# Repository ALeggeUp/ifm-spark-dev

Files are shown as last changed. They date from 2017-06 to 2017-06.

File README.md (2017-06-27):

# IFM Spark Dev Board

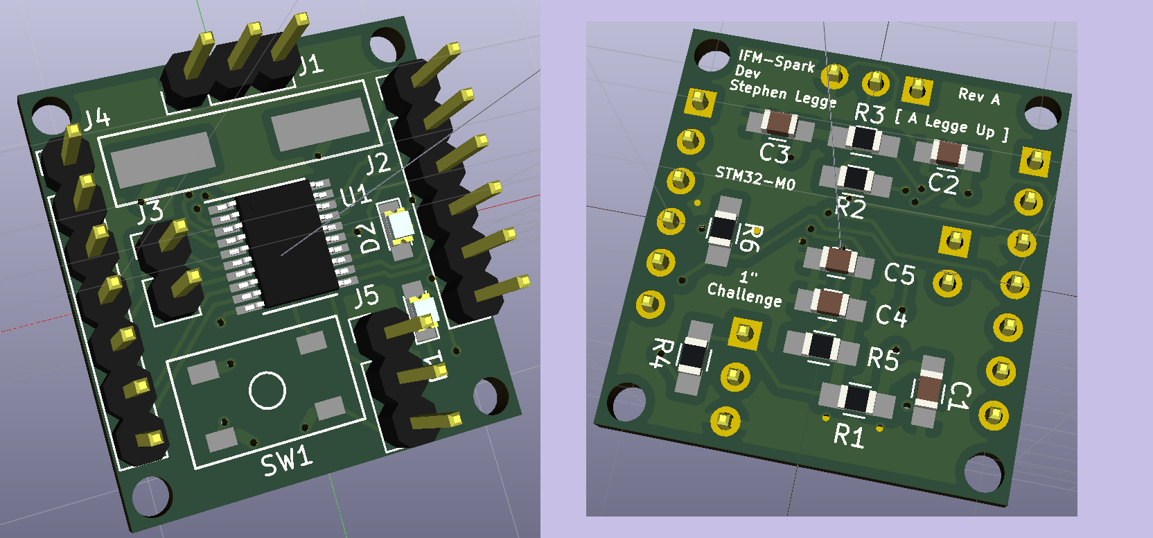
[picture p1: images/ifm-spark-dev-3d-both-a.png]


What is it?
-----------

IFM Spark Dev Board is a minimal Cortex-M0 dev board for experimentation.
The firmware is an example project that uses Gradle to build and test an embedded application.
It uses the examples included with the CppUTest project to show how it would work, the
embedded application doesn't do anything other than contain the objects to test.

Contributors
------------

* [Stephen Legge](https://github.com/slegge)

System requirements
-------------------

Gradle requires Java, but with the included gradlew that should be all that is needed
to build the firmware image.  This project as part of its initialization should pull
down the toolchain needed to build the firmware image.

For each operating system the requirements are similar, generally a Gcc or Clang
toolchain needs to be available for Gradle to use to build the tests.

In Windows, a standard install of Cygwin with gcc toolchain has been tested.

In Mac OS X, a default install of Xcode provides the Clang toolchain.

In Linux, standard gcc/g++ devel packages usually work fine.

Building
--------

If you have Gradle 3.0+ installed, you can just use

`gradle clean build`

or to use the bundled gradlew (Gradle Wrapper) use:

`./gradlew clean build`

Executing
---------

The Gradle build will create the firmware image and the CppUTest unit test runner.
The firmware image is meant to be loaded on the hardware, you'll need to load it
onto the hardware manually.  With an mbed board like a Nucleo board, it is just a
matter of copying the image to the mass storage device.

The CppUTest unit test runner is called utestrunner located under build/utestrunner/...

# License

This work is licensed under the Creative Commons Attribution 4.0 International License. To view a copy of this license, visit http://creativecommons.org/licenses/by/4.0/ or send a
letter to Creative Commons, PO Box 1866, Mountain View, CA 94042, USA.

Disclaimer
----------

THIS SOFTWARE IS PROVIDED BY THE COPYRIGHT HOLDERS AND CONTRIBUTORS "AS IS"
AND ANY EXPRESS OR IMPLIED WARRANTIES, INCLUDING, BUT NOT LIMITED TO, THE
IMPLIED WARRANTIES OF MERCHANTABILITY AND FITNESS FOR A PARTICULAR PURPOSE
ARE DISCLAIMED. IN NO EVENT SHALL THE COPYRIGHT OWNER OR CONTRIBUTORS BE
LIABLE FOR ANY DIRECT, INDIRECT, INCIDENTAL, SPECIAL, EXEMPLARY, OR
CONSEQUENTIAL DAMAGES (INCLUDING, BUT NOT LIMITED TO, PROCUREMENT OF
SUBSTITUTE GOODS OR SERVICES; LOSS OF USE, DATA, OR PROFITS; OR BUSINESS
INTERRUPTION) HOWEVER CAUSED AND ON ANY THEORY OF LIABILITY, WHETHER IN
CONTRACT, STRICT LIABILITY, OR TORT (INCLUDING NEGLIGENCE OR OTHERWISE)
ARISING IN ANY WAY OUT OF THE USE OF THIS SOFTWARE, EVEN IF ADVISED OF THE
POSSIBILITY OF SUCH DAMAGE.

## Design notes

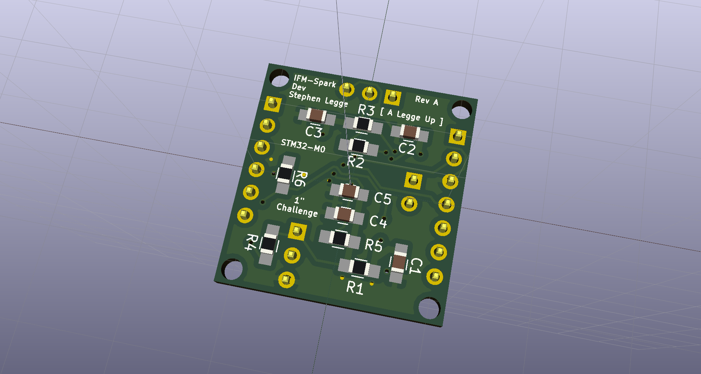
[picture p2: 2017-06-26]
images/ifm-spark-dev-3d-back-a.png

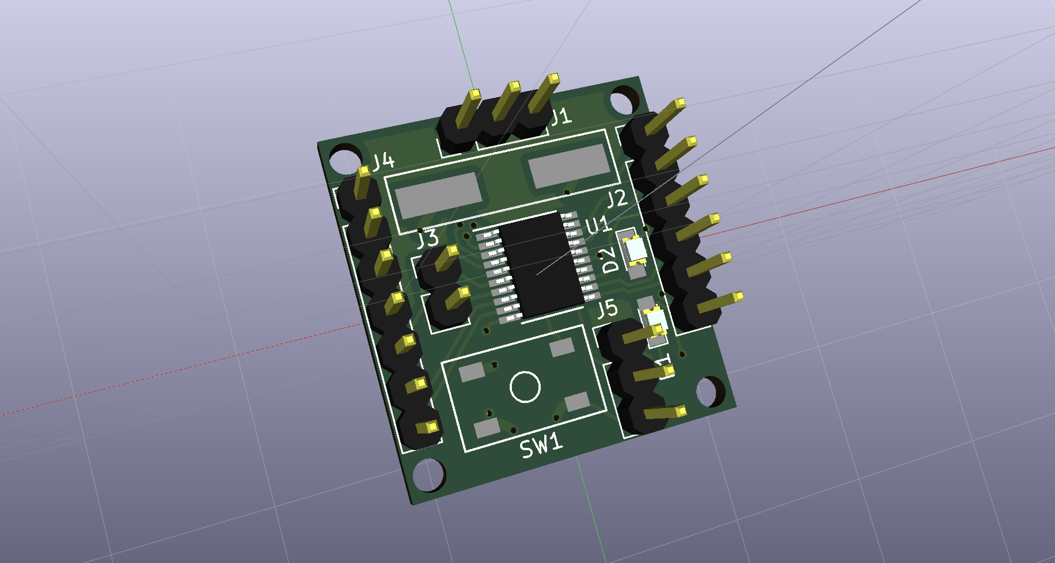
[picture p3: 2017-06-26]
images/ifm-spark-dev-3d-front-a.png

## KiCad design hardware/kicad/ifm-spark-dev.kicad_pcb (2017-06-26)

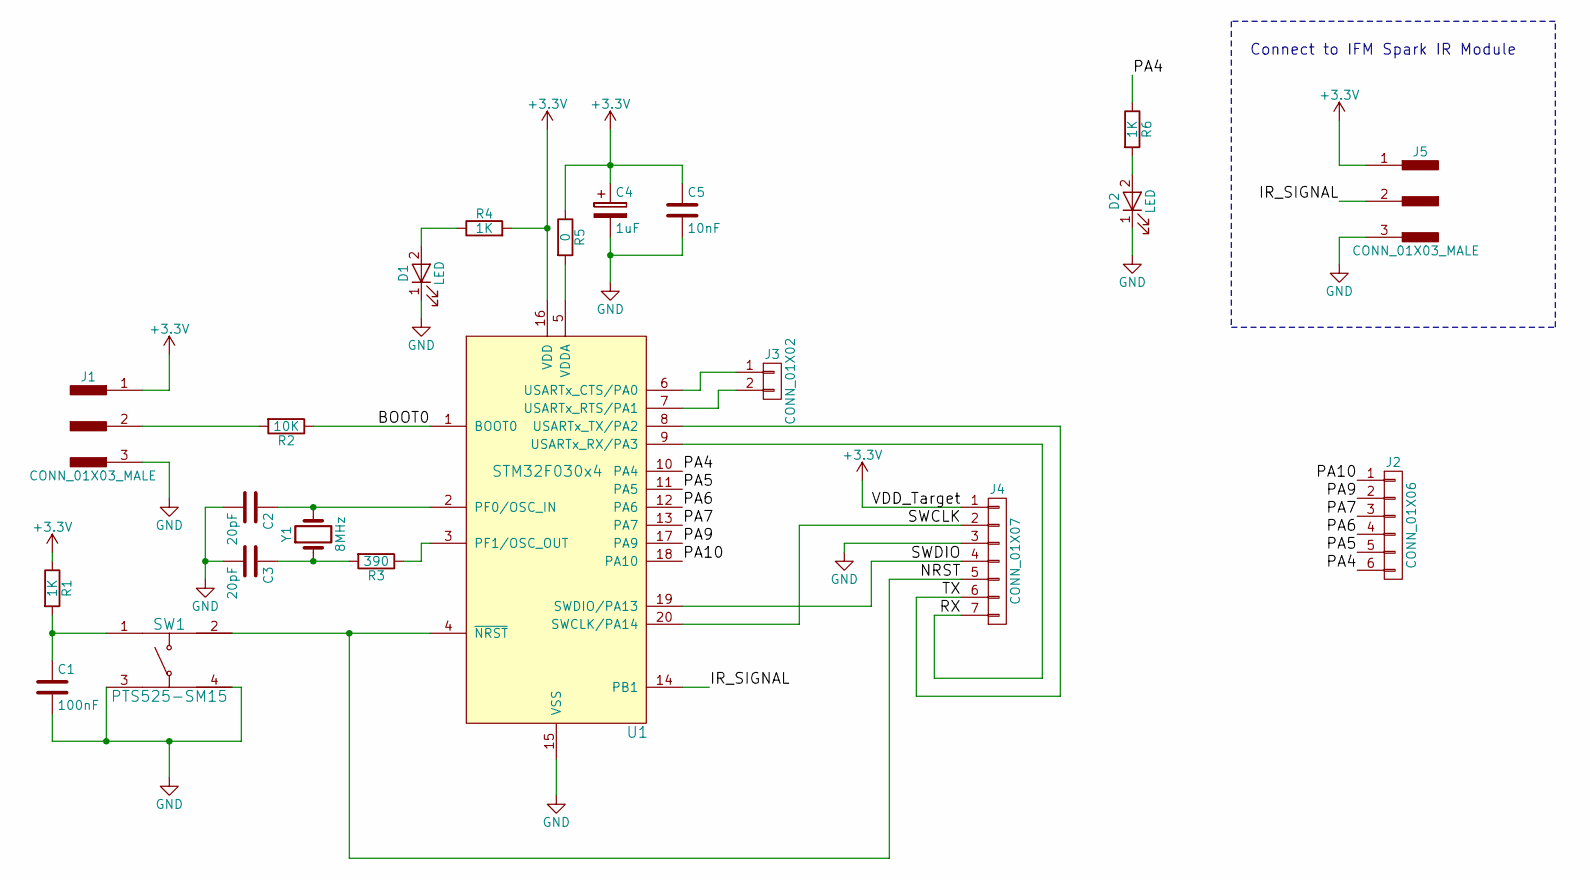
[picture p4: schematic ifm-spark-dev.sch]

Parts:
C1: 100nF; C_0805_HandSoldering
C2, C3: 20pF; C_0805_HandSoldering
C4: 1uF; C_0805_HandSoldering
C5: 10nF; C_0805_HandSoldering
D1, D2: LED; LED_0805
J1, J5: CONN_01X03_MALE; Pin_Header_Straight_1x03_Pitch2.54mm
J2: CONN_01X06; Pin_Header_Straight_1x06_Pitch2.54mm
J3: CONN_01X02; Pin_Header_Straight_1x02_Pitch2.54mm
J4: CONN_01X07; Pin_Header_Straight_1x07_Pitch2.54mm
R1, R4, R6: 1K; R_0805_HandSoldering
R2: 10K; R_0805_HandSoldering
R3: 390; R_0805_HandSoldering
R5: 0; R_0805_HandSoldering
SW1: PTS525-SM15; PTS525_SM15_SMTR2_LFS; MPN PTS525SM15SMTR2 LFS
U1: STM32F030x4; TSSOP-20_4.4x6.5mm_Pitch0.65mm; MPN STM32F030F4P6
Y1: 8MHz; ABLS-8.000MHZ-B4-T; MPN ABLS-8.000MHZ-B4-T

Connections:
+3V3: C4.1, C5.1, J1.1, J4.1, J5.1, R1.1, R4.2, R5.1, U1.16 (VDD)
/BOOT0: R2.1, U1.1 (BOOT0)
/IR_SIGNAL: J5.2, U1.14 (PB1)
/NRST: J4.5, SW1.2, U1.4 (~NRST)
/PA4: J2.6, R6.1, U1.10 (PA4)
/PA5: J2.5, U1.11 (PA5)
/PA6: J2.4, U1.12 (PA6)
/PA7: J2.3, U1.13 (PA7)
/PA9: J2.2, U1.17 (PA9)
/PA10: J2.1, U1.18 (PA10)
/RX: J4.7, U1.9 (USARTx_RX/PA3)
/SWCLK: J4.2, U1.20 (SWCLK/PA14)
/SWDIO: J4.4, U1.19 (SWDIO/PA13)
/TX: J4.6, U1.8 (USARTx_TX/PA2)
GND: C1.2, C2.2, C3.2, C4.2, C5.2, D1.1 (K), D2.1 (K), J1.3, J4.3, J5.3, SW1.3, SW1.4, U1.15 (VSS)
unnamed: C1.1, R1.2, SW1.1
unnamed: C2.1, U1.2 (PF0/OSC_IN), Y1.2
unnamed: C3.1, R3.2, Y1.1
unnamed: D1.2 (A), R4.1
unnamed: D2.2 (A), R6.2
unnamed: J1.2, R2.2
unnamed: J3.1, U1.6 (USARTx_CTS/PA0)
unnamed: J3.2, U1.7 (USARTx_RTS/PA1)
unnamed: R3.1, U1.3 (PF1/OSC_OUT)
unnamed: R5.2, U1.5 (VDDA)

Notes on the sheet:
Connect to IFM Spark IR Module

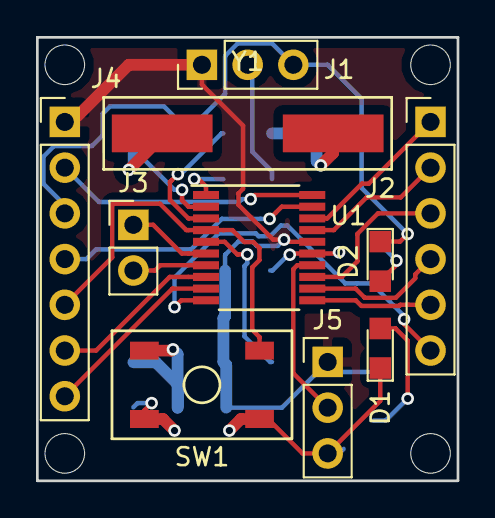
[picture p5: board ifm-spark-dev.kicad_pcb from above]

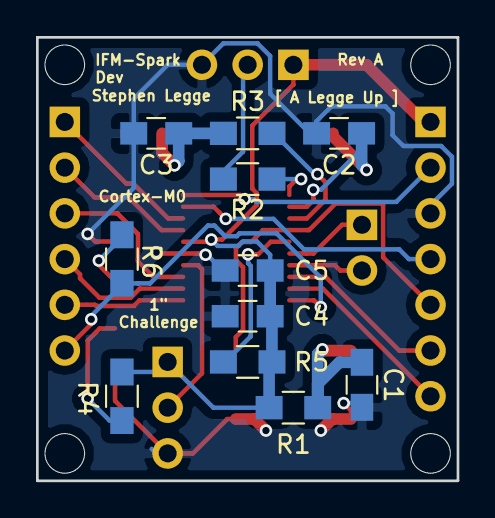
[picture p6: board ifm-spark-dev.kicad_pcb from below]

Board: 2 copper layers, 23.4 x 24.6 mm, 21 parts (11 on the bottom side), 25 nets.

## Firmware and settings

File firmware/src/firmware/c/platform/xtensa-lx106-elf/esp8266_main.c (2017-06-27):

#include <ets_sys.h>

#include "osapi.h"
#include "user_interface.h"

#include <os_type.h>
#include <gpio.h>
#include "driver/uart.h"

#define DELAY 1000

LOCAL os_timer_t hello_timer;
extern int ets_uart_printf(const char *fmt, ...);

LOCAL void ICACHE_FLASH_ATTR hello_cb(void *arg)
{
    ets_uart_printf("Hello World!\r\n");
}

/******************************************************************************
 * FunctionName : user_rf_cal_sector_set
 * Description  : SDK just reversed 4 sectors, used for rf init data and paramters.
 *                We add this function to force users to set rf cal sector, since
 *                we don't know which sector is free in user's application.
 *                sector map for last several sectors : ABBBCDDD
 *                A : rf cal
 *                B : at parameters
 *                C : rf init data
 *                D : sdk parameters
 * Parameters   : none
 * Returns      : rf cal sector
*******************************************************************************/
uint32 ICACHE_FLASH_ATTR
user_rf_cal_sector_set(void)
{
    enum flash_size_map size_map = system_get_flash_size_map();
    uint32 rf_cal_sec = 0;

    switch (size_map) {
        case FLASH_SIZE_4M_MAP_256_256:
            rf_cal_sec = 128 - 8;
            break;

        case FLASH_SIZE_8M_MAP_512_512:
            rf_cal_sec = 256 - 5;
            break;

        case FLASH_SIZE_16M_MAP_512_512:
        case FLASH_SIZE_16M_MAP_1024_1024:
            rf_cal_sec = 512 - 5;
            break;

        case FLASH_SIZE_32M_MAP_512_512:
        case FLASH_SIZE_32M_MAP_1024_1024:
            rf_cal_sec = 1024 - 5;
            break;

        default:
            rf_cal_sec = 0;
            break;
    }

    return rf_cal_sec;
}

void ICACHE_FLASH_ATTR
user_rf_pre_init(void)
{
}

void ICACHE_FLASH_ATTR
user_init(void)
{
    // Configure the UART
    uart_init(BIT_RATE_115200, BIT_RATE_115200);
    // Set up a timer to send the message
    // os_timer_disarm(ETSTimer *ptimer)
    os_timer_disarm(&hello_timer);
    // os_timer_setfn(ETSTimer *ptimer, ETSTimerFunc *pfunction, void *parg)
    os_timer_setfn(&hello_timer, (os_timer_func_t *)hello_cb, (void *)0);
    // void os_timer_arm(ETSTimer *ptimer,uint32_t milliseconds, bool repeat_flag)
    os_timer_arm(&hello_timer, DELAY, 1);
}

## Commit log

2017-05-24 New "IFM Spark Dev" project created
    [ifm-spark-dev.kicad_pcb, ifm-spark-dev.sch]
2017-05-24 Intending to use STM32F0 chip on this project, created symbol and added
2017-05-27 Pin labels for stm32 IC
2017-05-27 STM32 connected to crystal and pins to connect to external IR module
    [ifm-spark-dev.sch]
2017-06-24 Added switches symbols
2017-06-24 More connections, added a power LED indicator
    [ifm-spark-dev.sch]
2017-06-24 Untangle some wires
    [ifm-spark-dev.sch]
2017-06-24 Schematic cleanup
    [ifm-spark-dev.sch]
2017-06-24 Add net names to the ST-Link pins and connect the other two pins
    [ifm-spark-dev.sch]
2017-06-24 Add data fields for tactile switch
    [ifm-spark-dev.sch]
2017-06-24 Added an LED to PA4 and a pull-up to the switch
    [ifm-spark-dev.sch]
2017-06-24 Annotated schematic
    [ifm-spark-dev.sch]
2017-06-24 Associated all the easy passives and pin headers
    [ifm-spark-dev.sch]
2017-06-25 Created footprint for PTS525 SM15 SMTR2 LFS
2017-06-25 Added footprint into new resonators module for 8Mhz crystal
2017-06-25 Add meta details for crystal
    [ifm-spark-dev.sch]
2017-06-25 Associate crystal
    [ifm-spark-dev.sch]
2017-06-25 Fix unconnected crystal
    [ifm-spark-dev.sch]
2017-06-25 Initial rough layout of sub components to get a feel for layout
    [ifm-spark-dev.kicad_pcb]
2017-06-25 Re-order extra GPIO pins for easier layout
    [ifm-spark-dev.sch]
2017-06-25 Rough hookup of extra GPIOs
    [ifm-spark-dev.kicad_pcb]
2017-06-25 Update design rules to meet OSH Park minimums
    [ifm-spark-dev.kicad_pcb]
2017-06-26 First pass at connecting all nets on the board
    [ifm-spark-dev.kicad_pcb]
2017-06-26 Move some references around so they are easier to read
    [ifm-spark-dev.kicad_pcb]
2017-06-26 Added some labels and identifiers and cleaned up some tracks
    [ifm-spark-dev.kicad_pcb]
2017-06-26 Added images captured from KiCad 3D viewer
2017-06-27 Move hardware files into sub for visibility
    [ifm-spark-dev.kicad_pcb, ifm-spark-dev.sch]
